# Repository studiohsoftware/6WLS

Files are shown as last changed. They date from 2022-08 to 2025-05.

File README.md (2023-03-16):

# 6WLS Powered Busboard
This powered busboard design features a four layer PCB with a single dedicated ground plane and EMI shielded supplies. The result is a very low noise system with unprecedented preset bus stability.
</br>
</br>
There are two versions that fit Buchla cases. A 30W version for cases 18 spaces or less, and a 40W version for 24 space cases. The only difference between them are the supplies used, and the PCB footprints to support them (the board mounting in the boat is exactly the same.) The 30W version uses the Cincon EC6C, and the 40W version uses the Cincon EC7C. These supplies can be back ordered through either mouser.com or sager.com. 
</br>
</br>
There is a 40W "OTHER" version for cases using Roman bolt spacing (SAM/BOOPS/etc.) This board also uses the Cincon EC7C.
</br>
</br>
Passive busboards on Roman bolt spacing can be ordered through Osh Park here https://oshpark.com/projects/a7F1rsy2
</br>
</br>
6WLS-40 (40W version) with Cincon EC7C supplies.
6WLS-40 (40W version) with Cincon EC7C supplies 6WLS-40W

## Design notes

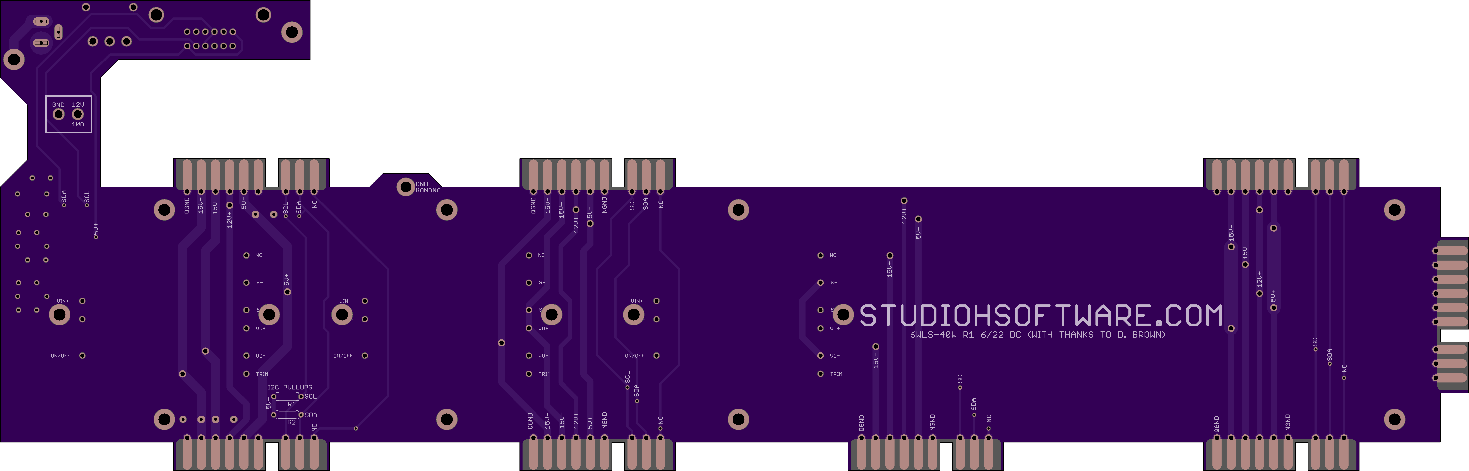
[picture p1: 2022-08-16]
6WLS-40W-bottom.png

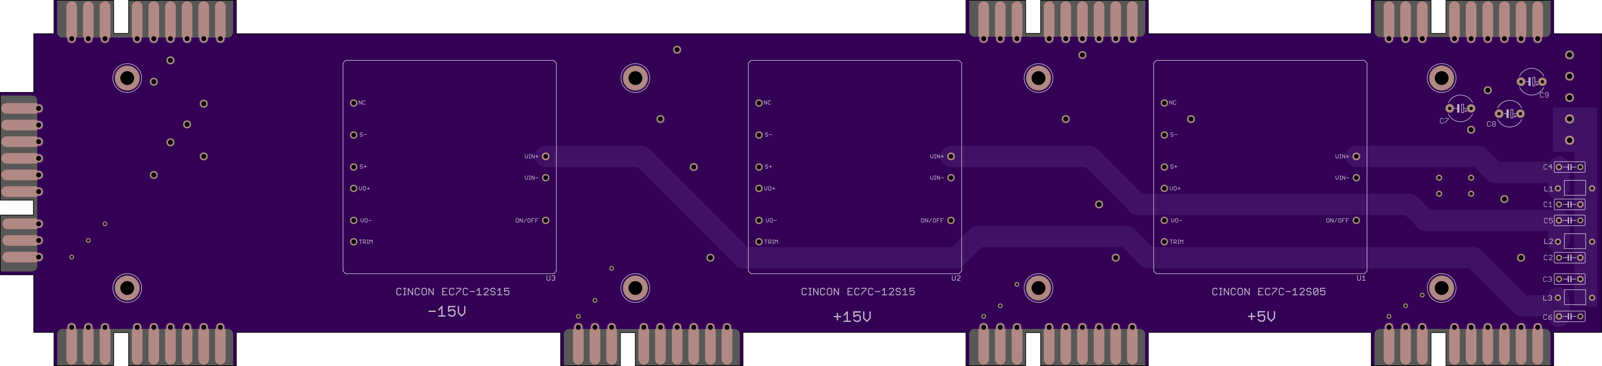
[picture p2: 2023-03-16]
6WLS-40W-OTHER-top.png

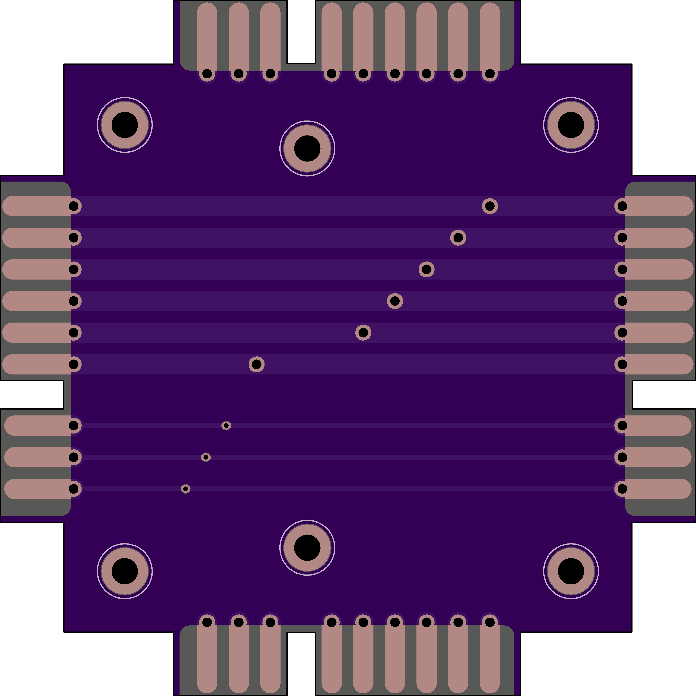
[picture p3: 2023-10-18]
2WLS-PASSIVE-top.png

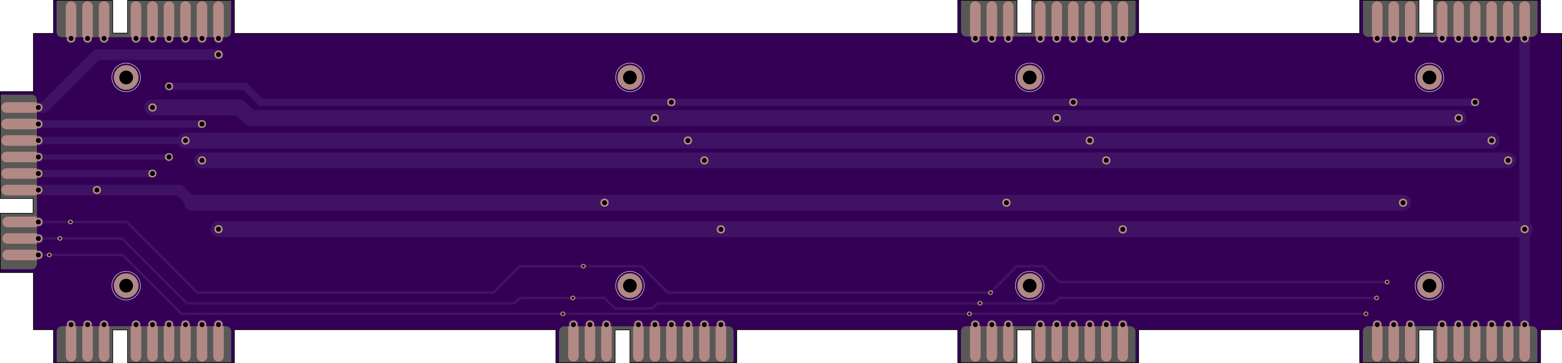
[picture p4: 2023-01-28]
6WLS-PASSIVE-top.png

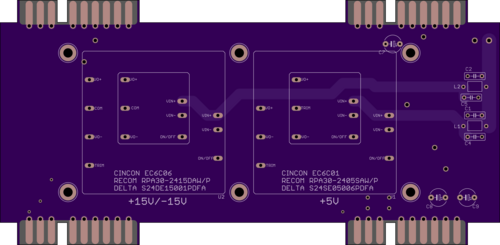
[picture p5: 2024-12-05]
2WLS-30W-top.png

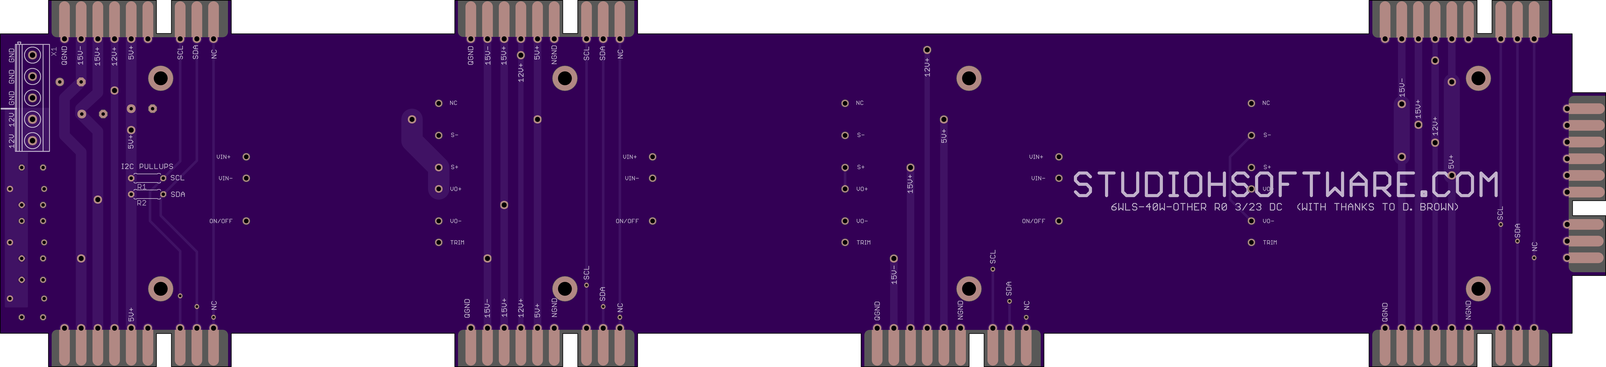
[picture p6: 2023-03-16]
6WLS-40W-OTHER-bottom.png

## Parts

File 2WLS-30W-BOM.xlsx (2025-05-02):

Qty | Value | Parts | Description | MF | MPN
4 | 100n | C1, C2, C4, C5 | Ceramic CAPACITOR
2 | 1k | R1, R2 | RESISTOR
3 | 47u | C7, C8,C9 | POLARIZED ALUM CAPACITOR
2 | BEAD | L1, L2 | Inductor | LAIRD | 28L0138-80R-10
1 | DCDCMULT6 | U1 | 5V DCDC Converter | Cincon | EC6C01
1 | DCDCMULT6D | U2 | 15V DCDC Dual Converter | Cincon | EC6C06
1 | MKDSN | MKDSN | Terminal Block | PHOENIX | 1729128

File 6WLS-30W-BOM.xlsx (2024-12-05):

Qty | Value | Parts | Description | MF | MPN
1 |  | SV1 | PIN HEADER (mount with two 4-40 x 1/2" machine screws) | SULLINS | EBC06DRAS
6 | 100n | C1, C2, C3, C4, C5, C6 | Ceramic CAPACITOR
1 | 12VDC-8A | J1 | DC POWER JACK | TENSILITY | 54-00167
2 | 1k | R1, R2 | RESISTOR
3 | 47u | C7, C8, C9 | POLARIZED ALUM CAPACITOR
3 | BEAD | L1, L2, L3 | Inductor | LAIRD | 28L0138-80R-10
1 | DCDCMULT6 | U1 | 5V DCDC Converter | Cincon | EC6C01
2 | DCDCMULT6 | U2, U3 | 15V DCDC Converter (see also Recom/Delta alternates on PCB) | Cincon | EC6C03
1 | SPDTTHRU | SW1 | SPDT Switch | NKK | MS13ASG30
1 | MKDSN | MKDSN | Terminal Block | PHOENIX | 1729128

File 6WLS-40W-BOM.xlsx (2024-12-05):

Qty | Value | Device | Package | Parts | Description | MF | MPN
1 |  | MA06-2CARD | EBC06DRAS | SV1 | PIN HEADER | SULLINS | EBC06DRAS
6 | 100n | C-US050-025X075 | C050-025X075 | C1, C2, C3, C4, C5, C6 | CAPACITOR, American symbol
1 | 12VDC-8A | BARREL55 | BARREL | J1 | DC POWER JACK | TENSILITY | 54-00167
2 | 1k | R-US_0207/7 | 0207/7 | R1, R2 | RESISTOR, American symbol
3 | 47u | CPOL-USE5-6 | E5-6 | C7, C8, C9 | POLARIZED CAPACITOR, American symbol
3 | BEAD | L | BEAD | L1, L2, L3 | Inductor | LAIRD | 28L0138-80R-10
1 | DCDCEC7C01 | DCDCEC7C01 | EC7C | U1 | DCDC Converter | CINCON | EC7C-12S05
2 | DCDCEC7C03 | DCDCEC7C03 | EC7C | U2, U3 | DCDC Converter | CINCON | EC7C-12S15
1 | SPDTTHRU | SPDTTHRU | SPDT-THRU | SW1 | SPDT Switch | NKK | MS13ASG30
1 | MKDSN | MKDSN | MKDSN | X1 | Terminal Block | PHOENIX | 1729128

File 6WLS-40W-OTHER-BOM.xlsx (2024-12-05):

Qty | Value | Device | Package | Parts | Description | MF | MPN | Z_DIGIKEY | Z_MOUSER
1 | MKDSN | MKDSN | MKDSN | X1 | Terminal Block | PHOENIX | 1729157 | 277-1250-ND
6 | 100n | C-US050-025X075 | C050-025X075 | C1, C2, C3, C4, C5, C6 | CAPACITOR, American symbol
2 | 1k | R-US_0207/7 | 0207/7 | R1, R2 | RESISTOR, American symbol
3 | 47u | CPOL-USE5-6 | E5-6 | C7, C8, C9 | POLARIZED CAPACITOR, American symbol
3 | BEAD | L | BEAD | L1, L2, L3 | Inductor | LAIRD | 28L0138-80R-10 | 240-2513-2-ND
1 | DCDCEC7C01 | DCDCEC7C01 | EC7C | U1 | DCDC Converter | CINCON | EC7C-12S05
2 | DCDCEC7C03 | DCDCEC7C03 | EC7C | U2, U3 | DCDC Converter | CINCON | EC7C-12S15

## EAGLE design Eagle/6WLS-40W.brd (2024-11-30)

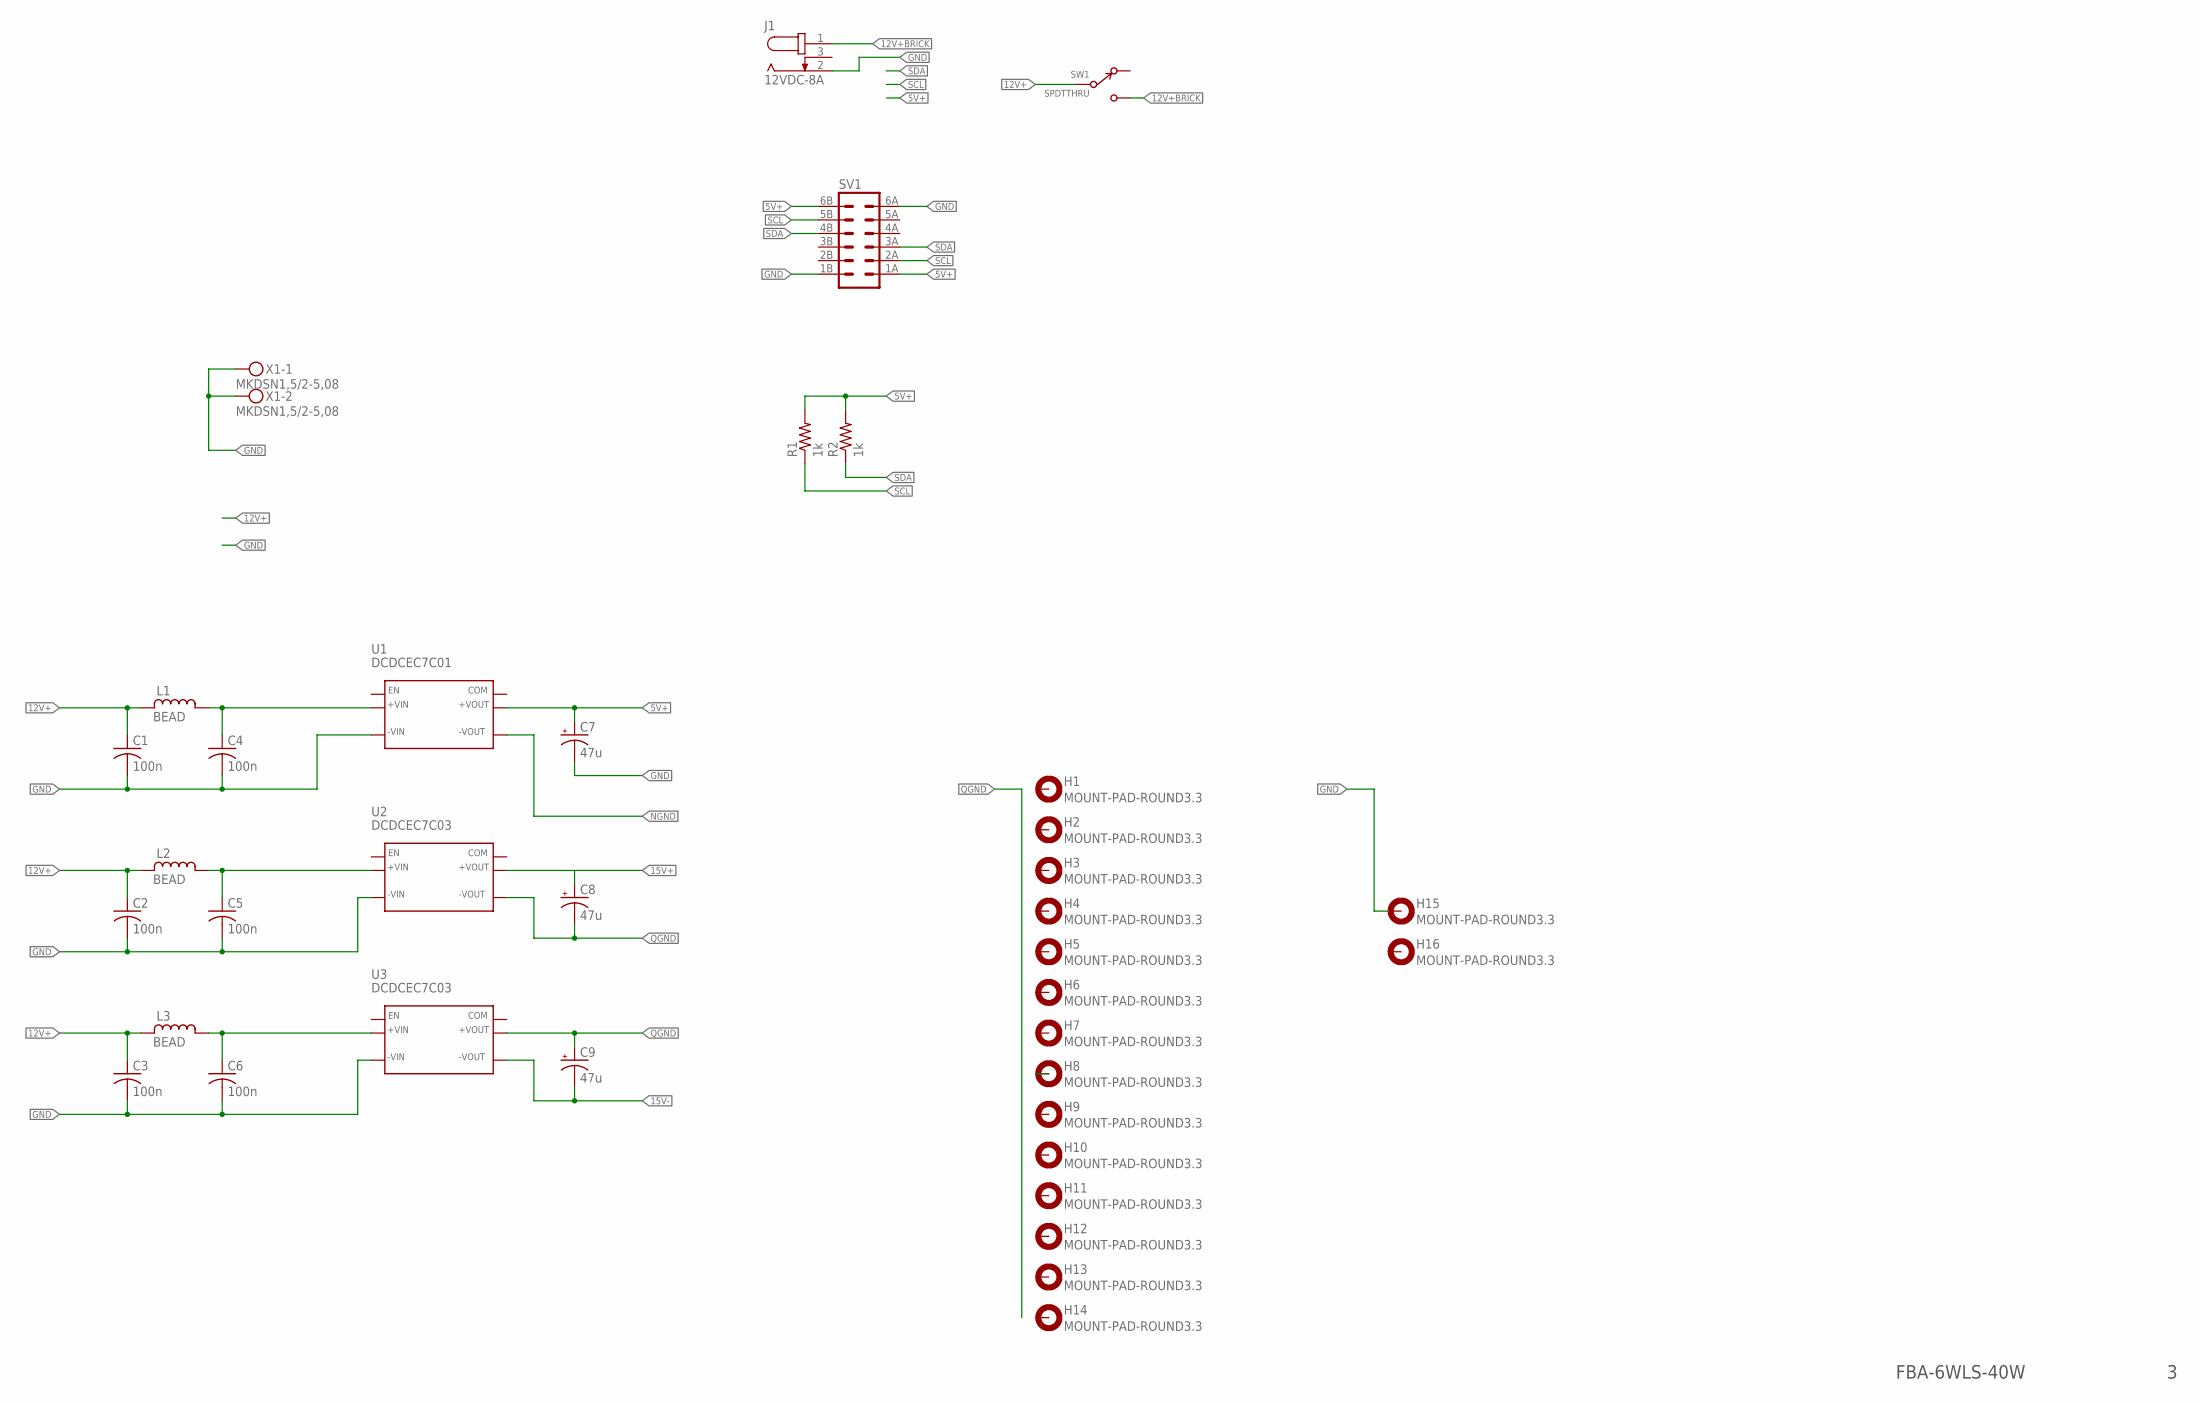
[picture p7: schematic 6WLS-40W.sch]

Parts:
C1, C2, C3, C4, C5, C6: 100n; C050-025X075
C7, C8, C9: 47u; E5-6
H1, H2, H3, H4, H5, H6, H7, H8, H9, H10, H11, H12, H13, H14, H15, H16: MOUNT-PAD-ROUND3.3; 3,3-PAD
J1: 12VDC-8A; BARREL
L1, L2, L3: BEAD
R1, R2: 1k; 0207/7
SV1: MA06-2CARD; EBC06DRAS
SW1: SPDTTHRU; SPDT-THRU
U1: DCDCEC7C01; EC7C
U2, U3: DCDCEC7C03; EC7C
X1: MKDSN1,5/2-5,08

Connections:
5V+: C7.+, R1.2, R2.2, SV1.1A (1), SV1.6B (12), U1.S+ (+VOUT), U1.VO+ (+VOUT)
12V+: C1.1, C2.1, C3.1, L1.1, L2.1, L3.1, SW1.C
12V+BRICK: J1.1, SW1.1
15V+: C8.+, U2.S+ (+VOUT), U2.VO+ (+VOUT)
15V-: C9.-, U3.S- (-VOUT), U3.VO- (-VOUT)
COM: U1.NC (COM), U2.NC (COM), U3.NC (COM)
GND: C1.2, C2.2, C3.2, C4.2, C5.2, C6.2, C7.-, H15.B3,3, J1.2, SV1.1B (2), SV1.6A (11), U1.VIN- (-VIN), U2.VIN- (-VIN), U3.VIN- (-VIN), X1.1, X1.2
unnamed: C5.1, L2.2 (4), U2.VIN+ (+VIN)
unnamed: C6.1, L3.2 (4), U3.VIN+ (+VIN)
unnamed: C4.1, L1.2 (4), U1.VIN+ (+VIN)
NGND: U1.S- (-VOUT), U1.VO- (-VOUT)
QGND: C8.-, C9.+, U2.S- (-VOUT), U2.VO- (-VOUT), U3.S+ (+VOUT), U3.VO+ (+VOUT)
SCL: R1.1, SV1.2A (3), SV1.5B (10)
SDA: R2.1, SV1.3A (5), SV1.4B (8)

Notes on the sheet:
FBA-6WLS-40W

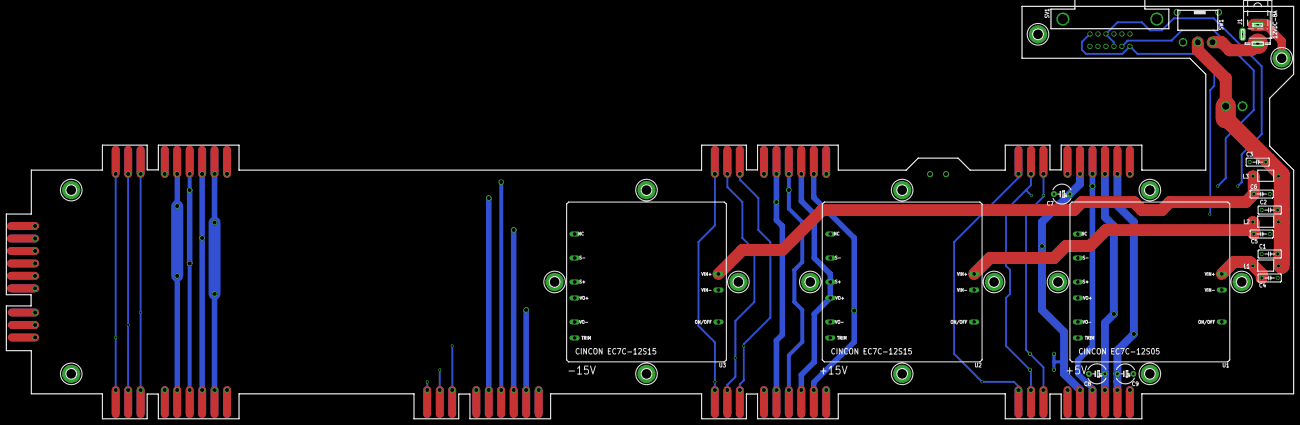
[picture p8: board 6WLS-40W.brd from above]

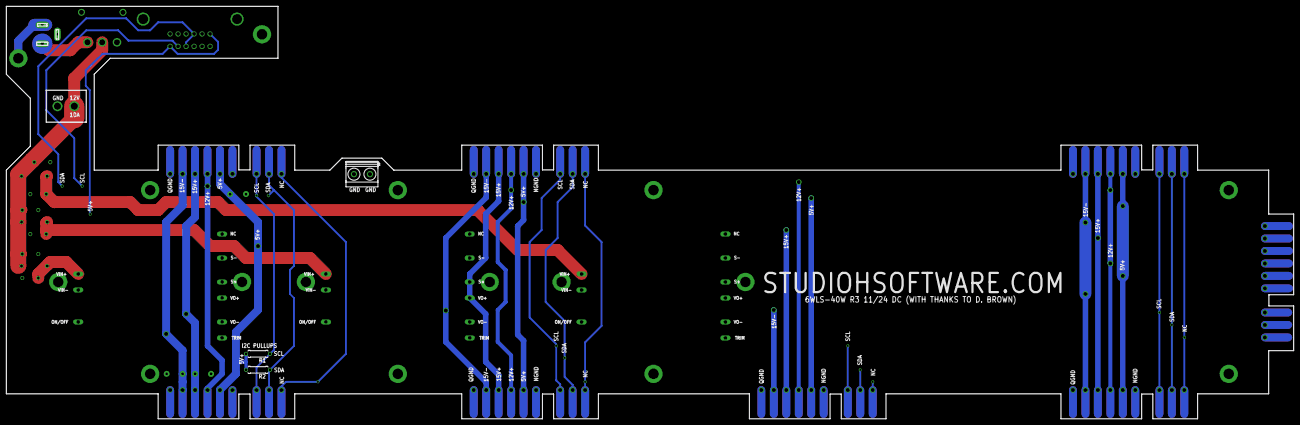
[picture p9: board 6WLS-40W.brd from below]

Board: 4 copper layers, 409.3 x 131.1 mm, 37 parts (3 on the bottom side), 14 nets.

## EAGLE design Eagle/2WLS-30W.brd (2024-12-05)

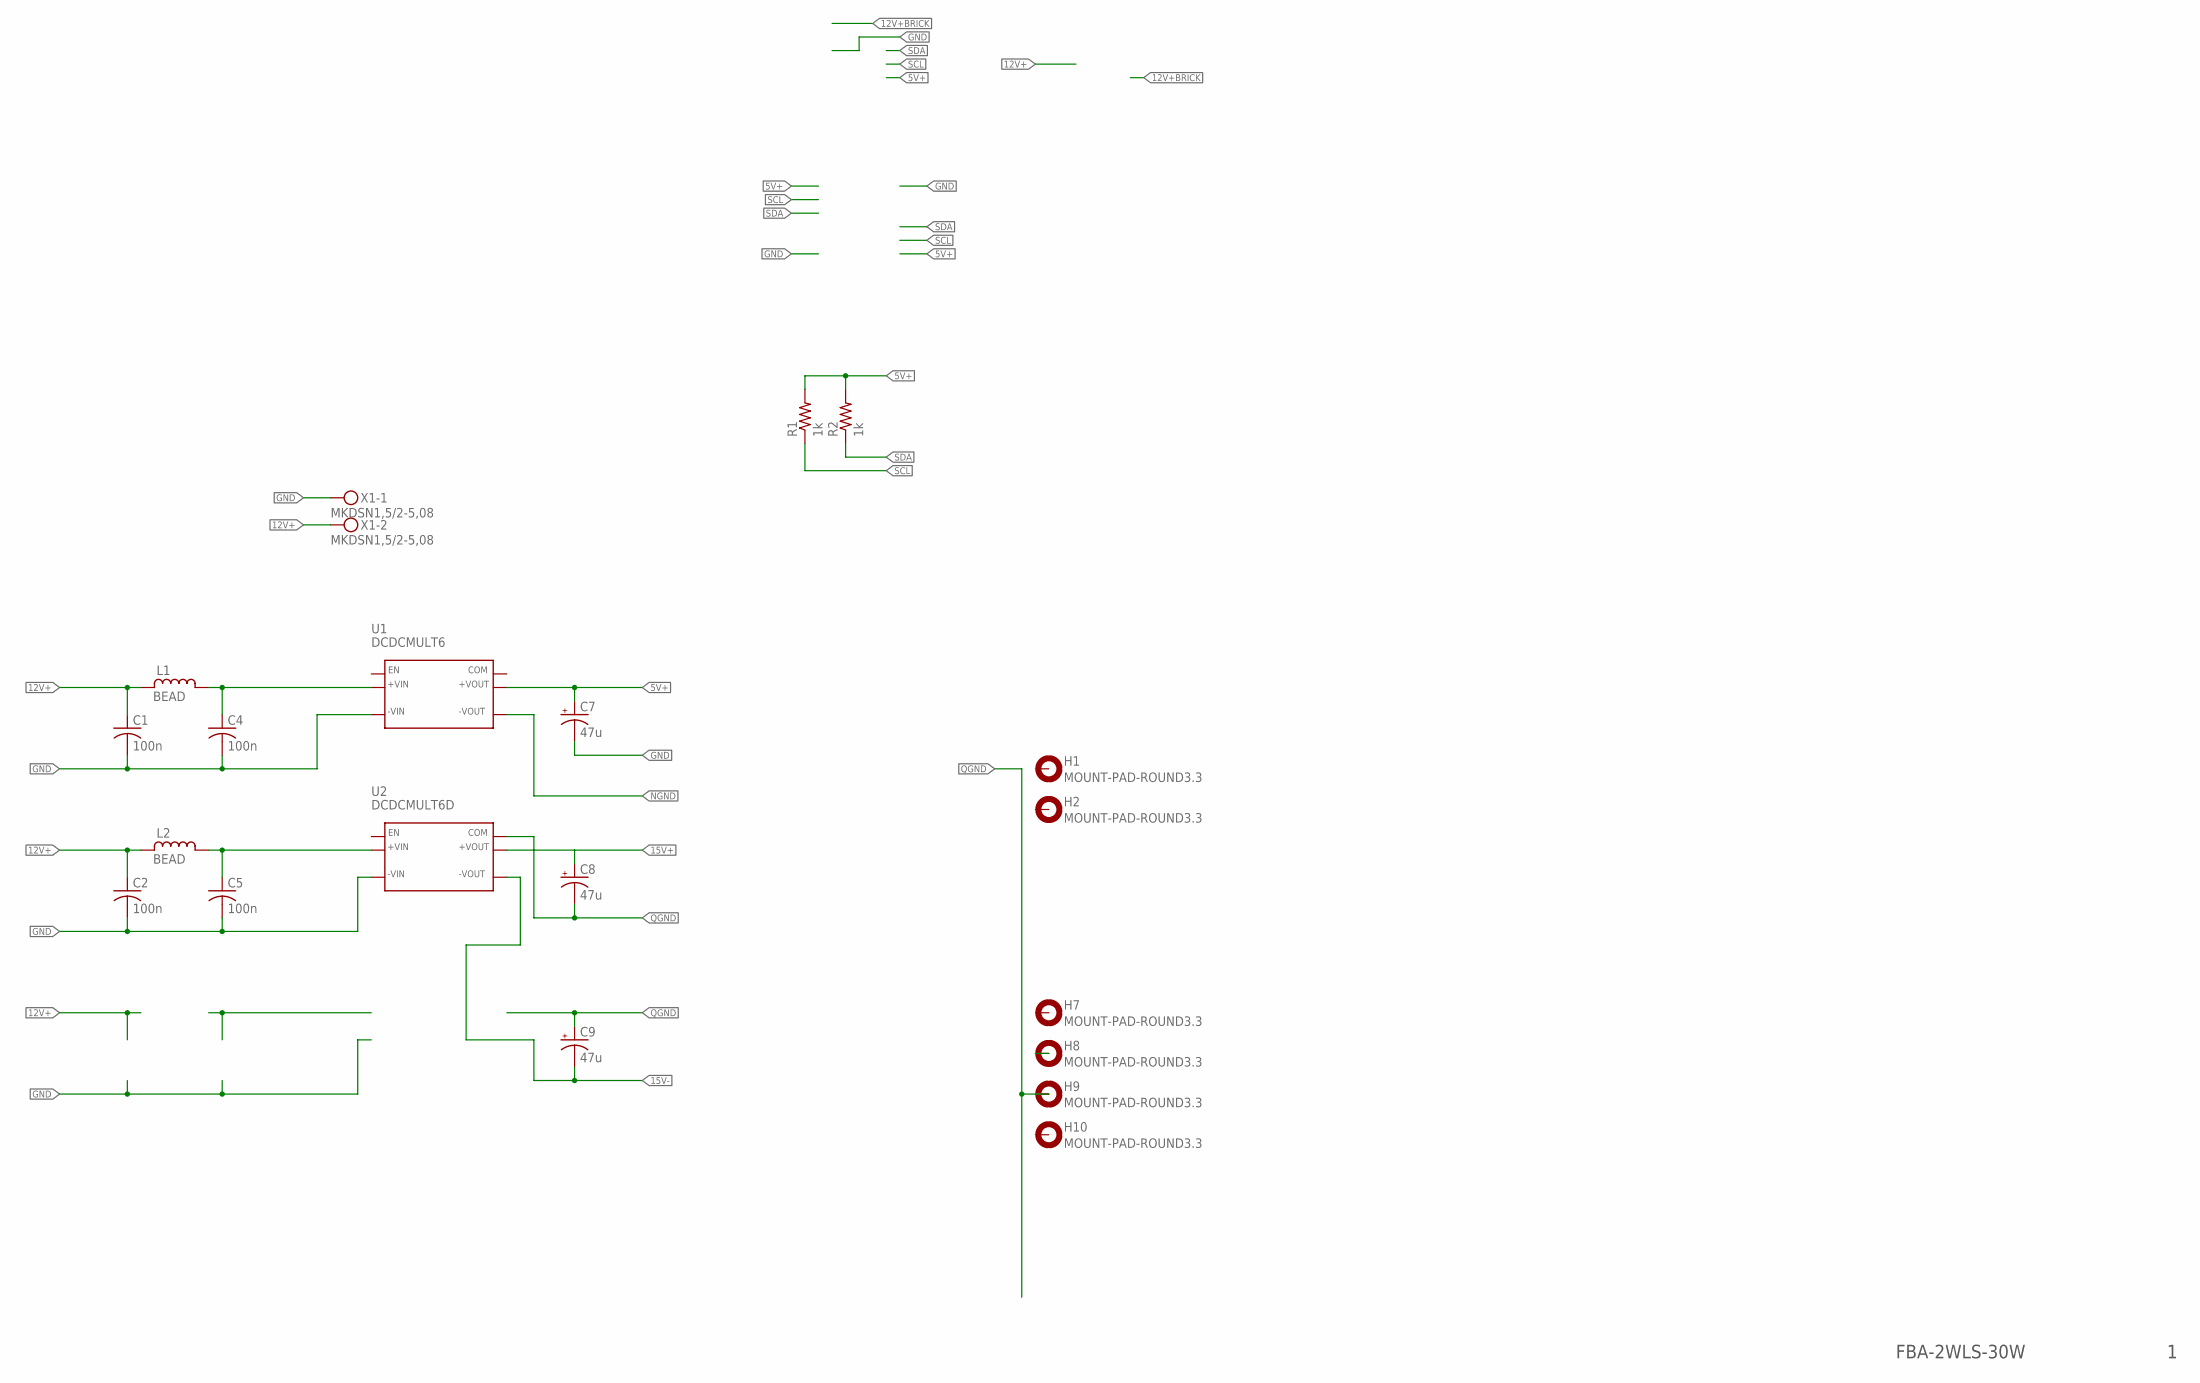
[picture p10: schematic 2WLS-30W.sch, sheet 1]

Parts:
C1, C2, C4, C5: 100n; C050-025X075
C7, C8, C9: 47u; E5-6
H1, H2, H7, H8, H9, H10: MOUNT-PAD-ROUND3.3; 3,3-PAD
L1, L2: BEAD
R1, R2: 1k; 0207/7
U1: DCDCMULT6; EC6CMULT
U2: DCDCMULT6D; EC6CMULTD
X1: MKDSN1,5/2-5,08

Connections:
5V+: C7.+, R1.2, R2.2, U1.VO1+ (+VOUT), U1.VO+ (+VOUT)
12V+: C1.1, C2.1, L1.1, L2.1, X1.2
15V+: C8.+, U2.VO1+ (+VOUT), U2.VO+ (+VOUT)
15V-: C9.-, U2.VO1- (-VOUT), U2.VO- (-VOUT)
COM: U1.TRIM (COM), U1.TRIM1 (COM)
GND: C1.2, C2.2, C4.2, C5.2, C7.-, U1.VIN1- (-VIN), U1.VIN- (-VIN), U2.VIN1- (-VIN), U2.VIN- (-VIN), X1.1
unnamed: C5.1, L2.2 (4), U2.VIN1+ (+VIN), U2.VIN+ (+VIN)
unnamed: C4.1, L1.2 (4), U1.VIN1+ (+VIN), U1.VIN+ (+VIN)
NGND: U1.VO1- (-VOUT), U1.VO- (-VOUT)
QGND: C8.-, C9.+, U2.COM, U2.COM1 (COM)
SCL: R1.1
SDA: R2.1

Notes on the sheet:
FBA-2WLS-30W

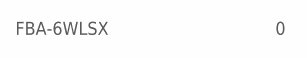
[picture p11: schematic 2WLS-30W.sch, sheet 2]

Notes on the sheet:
FBA-6WLSX

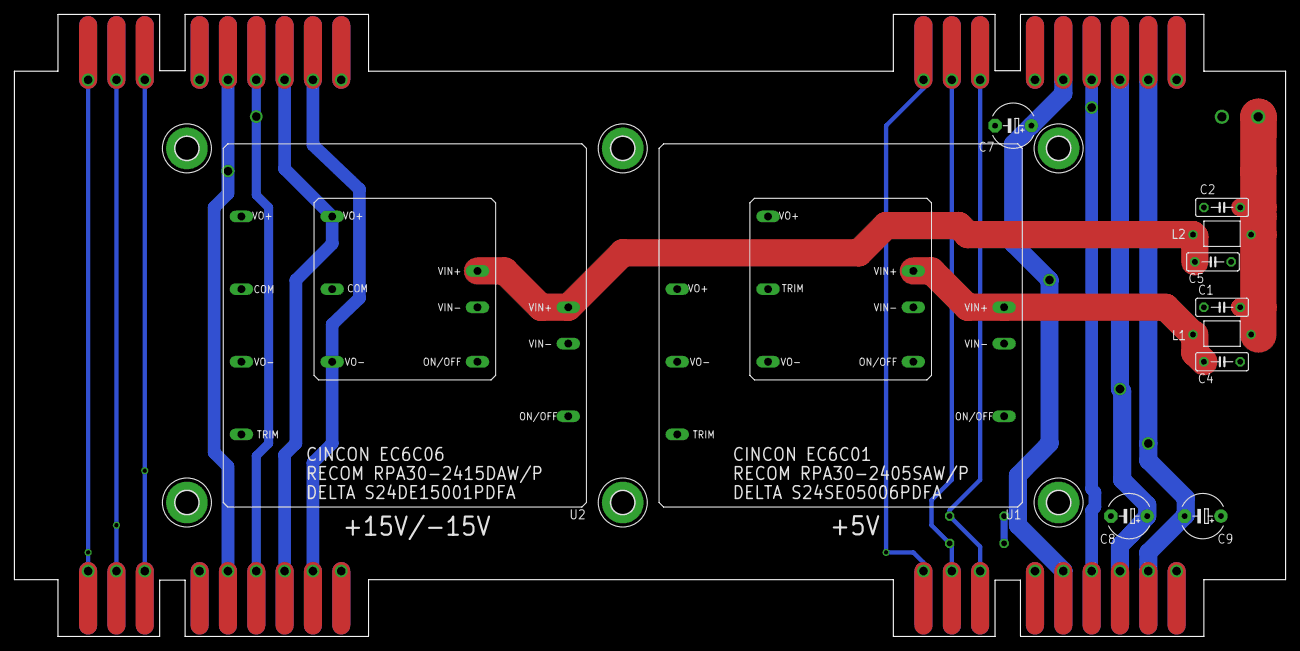
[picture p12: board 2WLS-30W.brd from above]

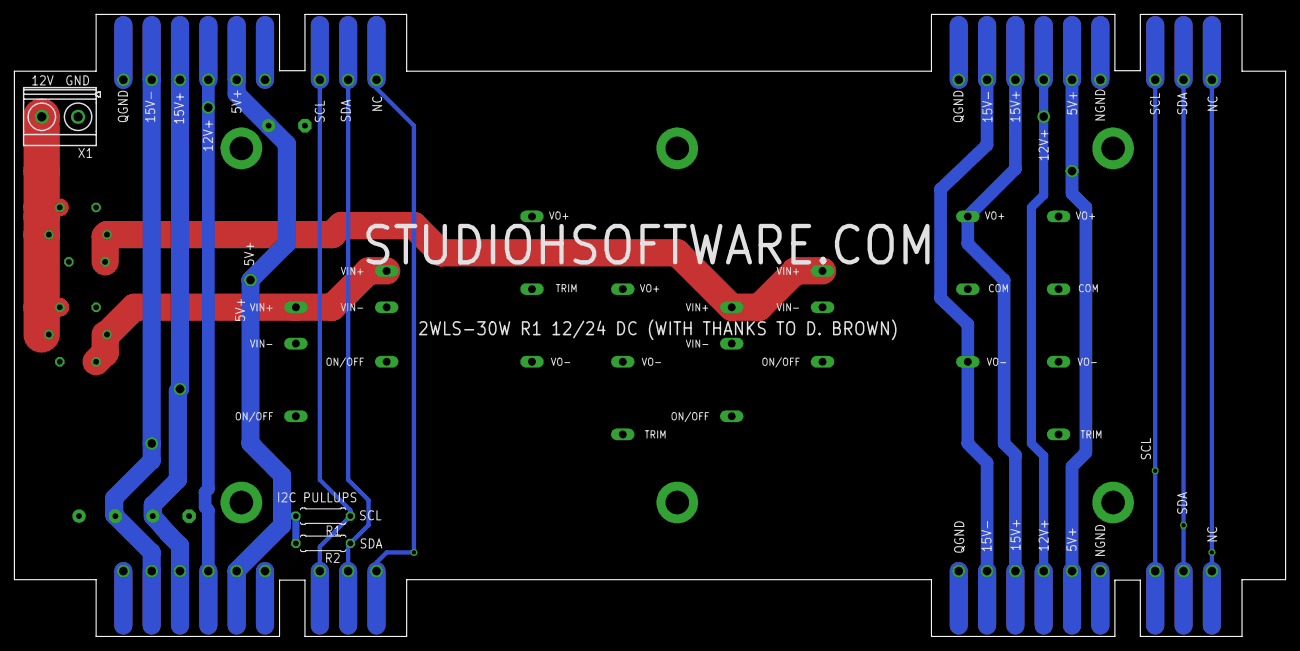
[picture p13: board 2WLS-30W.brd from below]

Board: 4 copper layers, 177.8 x 87.0 mm, 20 parts (3 on the bottom side), 10 nets.

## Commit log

2022-05-27 Add BOM
    [6WLS-30W-BOM.xlsx]
2022-06-19 Add images of 30W board.
2022-08-16 Add 40W Eagle files.
    [6WLS-40W.brd, 6WLS-40W.sch]
2022-08-16 Add 40W board images.
2022-09-28 Add Gerber ZIP Files
    Gerber files for 30 Watt version and 40 Watt version.
2022-09-28 Add BOM files.
    [6WLS-40W-BOM.xlsx]
2022-09-28 Update BOM
2022-09-28 Create Gerbers Directory
2022-09-28 Add Gerber ZIP Files
2022-12-06 Add CHB Design
    [6WLS-CHB-BOM.xlsx]
2022-12-10 Bigger terminal block.
    [6WLS-CHB-BOM.xlsx]
2023-01-20 Add photos of 40W board.
2023-01-28 Add passive boards for Roman/SAM/Boops/etc.
2023-03-07 Move supplies down to clear upper mounting screws.
    [6WLS-40W.brd]
2023-03-07 Move supplies down to clear mounting screws.
2023-03-16 Add 6WLS-40W-OTHER for ROMAN/SAM/BOOPS/etc.
    [6WLS-40W-OTHER.xlsx]
2023-10-18 Added files for 2WLS passive board.
    [2WLS-PASSIVE.brd, 2WLS-PASSIVE.sch]
2024-11-30 Add more copper for supply pins.
    [6WLS-40W-OTHER.brd, 6WLS-40W-OTHER.sch, 6WLS-40W.brd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]
2024-11-30 Add terminal block for ground banana.
    [6WLS-40W-BOM.xlsx]
2024-11-30 Add drill files.
2024-12-05 Add 2WLS design, terminal blocks for ground banana
    New board 2WLS-30W for The Beast UK two space boat. Also add terminal blocks for ground bananas on Buchla format 30W and 40W boards. Correct filename on OTHER BOM.
    [2WLS-30W-BOM.xlsx, 6WLS-30W-BOM.xlsx, 6WLS-40W-BOM.xlsx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]
2024-12-05 Add board for two space boat.
    New board 2WLS-30W for The Beast UK two space boat.
    [2WLS-30W.brd, 2WLS-30W.sch]
2024-12-05 Delete 6WLS-40W.brd
    Wrong directory
    [6WLS-40W.brd]
2024-12-05 Delete 6WLS-40W.sch
    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
    [6WLS-40W.sch]
2024-12-05 Delete 6WLS-40W-OTHER.brd
    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
    [6WLS-40W-OTHER.brd]
2024-12-05 Delete 6WLS-40W-OTHER.sch
    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
    [6WLS-40W-OTHER.sch]
2024-12-05 Delete 6WLS-40W-OTHER.xlsx
    Renamed to 6WLS-40W-OTHER-BOM.xlsx
    [6WLS-40W-OTHER.xlsx]
2024-12-05 Larger copper pads for supply pins.
    Switch to larger, oblong pads for supply pins. Thanks to Prism Circuits.
    [6WLS-30W.brd, 6WLS-30W.sch, 6WLS-40W-OTHER.brd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]
2024-12-05 Add board for two space boat.
    Add new board 2WLS-30W for The Beast UK two space boat. Also larger copper pad size for supply pins on 6WLS-30W board.
2025-05-02 Fix quantities on 2WLS-30W-BOM
    [2WLS-30W-BOM.xlsx]
2025-05-23 Add 2WLS EXTENDER and fix 2WLS PASSIVE solder mask
2025-05-23 Add 2WLS EXTENDER and fix 2WLS PASSIVE silkscreen
    [2WLS-EXTENDER.brd, 2WLS-EXTENDER.sch, 2WLS-PASSIVE.brd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]
2025-06-28 Adjust dimensions to fit Keen case.
2025-12-06 Fix silkscreen
